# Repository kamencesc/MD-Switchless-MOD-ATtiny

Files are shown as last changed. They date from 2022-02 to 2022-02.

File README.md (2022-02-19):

# UNTESTED
Note: After programming the Attiny, the RST pin is used as a in/out pin, so you need to make (or buy) a High Voltage Programmer to fuse-reset as you can see there: (https://sites.google.com/site/wayneholder/attiny-fuse-reset)

# MD Switchless MOD ATtiny
Sega Mega Drive/Genesis Switchless mod with an ATtiny85

Similar to the Switchless Mod code for Sega Saturn (https://github.com/sebknzl/saturnmod), this code is writed from zero and works this way:

- It change between 3 regions, 1 = PAL (Default at first time that the code runs and you can change it if you wish), 2 = USA, 3 = JAPAN
- Short press of  the reset button does the region change (EU->USA->JAP->EU....)
- The region is saved to the internat EEPROM for the next boot
- Long press of the reset button (+2 seconds) does the reset

Code was typed in the Adrduino IDE, you can find the pins config on the source code.

There's an untested PCB desing for and easy installation, maybe it doesn't fit on all revision boards.

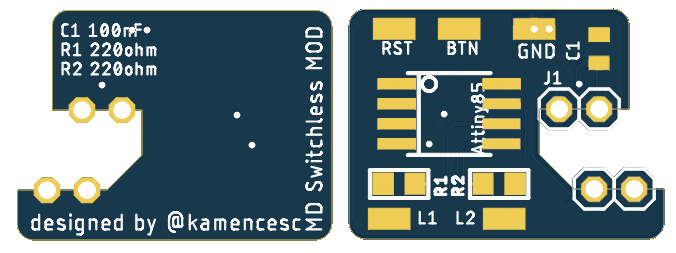
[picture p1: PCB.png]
PCB


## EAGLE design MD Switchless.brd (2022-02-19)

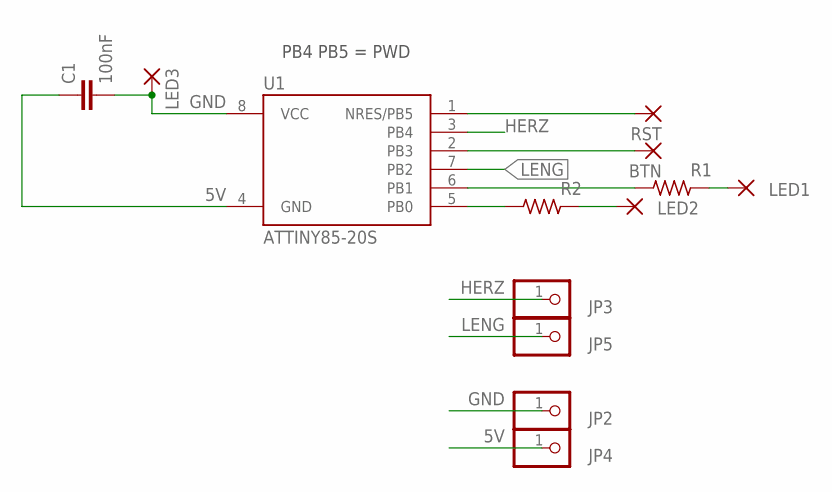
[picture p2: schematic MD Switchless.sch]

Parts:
BTN: WIREPADSMD1,27-254; SMD1,27-2,54
C1: 100nF; 0805
JP2, JP3, JP4, JP5: PINHD-1X1; 1X01
LED1, LED2, LED3: WIREPADSMD1,27-254; SMD1,27-2,54
R1, R2: R_0805; R0805
RST: WIREPADSMD1,27-254; SMD1,27-2,54
U1: ATTINY85-20S; SOIC8_EIAJ_208MIL

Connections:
5V: C1.1, JP4.1, U1.4 (GND)
BTN: BTN.1, U1.2 (PB3)
GND: C1.2, JP2.1, LED3.1, U1.8 (VCC)
HERZ: JP3.1, U1.3 (PB4)
L1: LED1.1, R1.2
L2: LED2.1, R2.2
LENG: JP5.1, U1.7 (PB2)
RL1: R1.1, U1.6 (PB1)
RL2: R2.1, U1.5 (PB0)
RST: RST.1, U1.1 (NRES/PB5)

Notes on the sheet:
PB4 PB5 = PWD

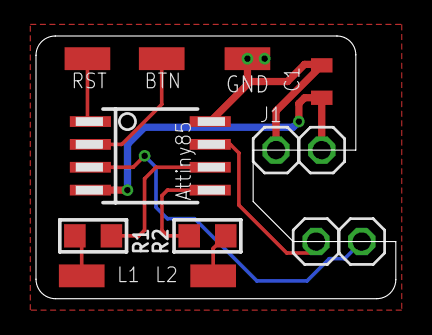
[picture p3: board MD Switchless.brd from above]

Board: 2 copper layers, 20.0 x 14.6 mm, 13 parts (0 on the bottom side), 10 nets.

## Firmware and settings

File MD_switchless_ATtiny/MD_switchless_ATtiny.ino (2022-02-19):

// Code for Attiny85
// Switchless mod for Megadrive
//
// Code by: Kamencesc
// Board by: Kamencesc
//
// Site: http://www.kamencesc.com/
// Git-hub: https://github.com/kamencesc/MD-Switchless-MOD-ATtiny
// 19-02-2021
//--------------------------------------------------------------------
//    * ATtiny25/45/85 pinout
//                 __  __
// RST      5/A0 -| 1`´8 |- VCC
// BTN      3/A3 -| 2  7 |- 2/A1    LENGUAGE
// HERZ     4/A2 -| 3  6 |- 1       LED1
//           GND -|_4__5_|- 0       LED2
//
//--------------------------------------------------------------------

#include <EEPROM.h>

//config reset pins
const int btn = 3;
const int rst = 5 ;
//config dual led pins
const int led1 = 1;
const int led2 = 0;
//config mode pins
const int country = 2;
const int herz = 4;

//Bicolor LED config
//1 = Common Anode
//0 = Common Catode
const int LEDs=0; 

int btnState = 0;
int btnPress = 0;

//config first region region: 1 for EU, 2 for USA, 3 for JAPAN
int region = 1;

int timepress = 0;

//eeprom
int address = 0;
int value;

void setup() {
  //config pinmodes

  //reset button
  pinMode(rst, OUTPUT);
  pinMode(btn, INPUT);
  //dual led
  pinMode(led1, OUTPUT);
  pinMode(led2, OUTPUT);
  //modes
  pinMode(country, OUTPUT);
  pinMode(herz, OUTPUT);

  value = EEPROM.read(address);
  if ((value > 0) && (value < 4)) {
        region=value;
  } else {
     EEPROM.write(address, region);
  }
  changeRegion(region);
}

void changeRegion (int val) {
  switch (val) {
    case 1:                         //EU
      digitalWrite(country, LOW );
      digitalWrite(herz, HIGH );
      digitalWrite(led1, LEDs ? LOW : HIGH );
      digitalWrite(led2, LEDs ? HIGH : LOW );
      EEPROM.write(address, region);
      region++;
    case 2:                         //USA
      digitalWrite(country, HIGH );
      digitalWrite(herz, HIGH );
      digitalWrite(led1, LEDs ? HIGH : LOW );
      digitalWrite(led2, LEDs ? HIGH : LOW );
      EEPROM.write(address, region);
      region++;
    case 3:                         //JAPAN
      digitalWrite(country, HIGH );
      digitalWrite(herz, LOW );
      digitalWrite(led1, LEDs ? HIGH : LOW );
      digitalWrite(led2, LEDs ? LOW : HIGH );
      EEPROM.write(address, region);
      region = 1;
  }
}

void loop() {
  btnState = digitalRead(btn);

  if (!btnState) {                  //GND = Reset is pressed
    while (!btnState) {             //while btn is pressed
      delay(200);                   //delay of 200ms
      timepress++;                  //timepress increment
      if (timepress >= 10) {        //if +200ms starts a LED animation
        if (timepress % 3) {        //LED change color each 600ms
            digitalWrite(led1, HIGH );
            digitalWrite(led2, LOW );
        } else {
            digitalWrite(led1, LOW );
            digitalWrite(led2, HIGH );
        }
      }
      btnState = digitalRead(btn);  //read btn again
    }
    if (timepress >= 10) {          //if timepress 10*200ms = 2000ms = 2 seconds
      digitalWrite(rst, LOW);       //send LOW to simulate reset press
      delay(10);                    //little delay
      digitalWrite(rst, HIGH);      //back to HIGH
    } else {
      changeRegion(region);         //timpress < 2 seconds than change region
    }
  }
}

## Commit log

2019-07-24 Code
    Code typed in Arduino IDE
2019-07-24 Add files via upload
    PCB size and traces width
    [MD Switchless.brd, MD Switchless.sch]
2019-07-24 Add files via upload
    minor changes
    [MD Switchless.brd]
2019-07-25 Add files via upload
    Wrong position on headers, now it fits perfect
    [MD Switchless.brd]
2019-07-25 Add files via upload
    ATtiny85 label on the wrong side
    [MD Switchless.brd]
2019-08-01 Add files via upload
    Minor changes, R1-3 now are 220ohm
    [MD Switchless.brd]
2020-11-16 Add files via upload
    Update a config const for a anode/catode LED
2022-02-19 Add files via upload
    traces and pinout changes
    [MD Switchless.brd, MD Switchless.sch]
2022-02-19 Add files via upload
    Code revision, change pinouts after PCB revision
2022-02-19 Add files via upload
    PCB render

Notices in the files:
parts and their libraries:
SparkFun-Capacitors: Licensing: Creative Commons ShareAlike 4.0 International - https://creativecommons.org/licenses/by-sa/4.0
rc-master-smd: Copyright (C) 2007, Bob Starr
